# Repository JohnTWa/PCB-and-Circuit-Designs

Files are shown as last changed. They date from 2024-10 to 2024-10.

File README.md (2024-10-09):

All of these designs will work, however, the ones labelled "(OLD)" are projects which hit a dead end or were replaced with other designs.

Designs which were replaced by different designs as part of the same project will have "(Version #, OLD)" in the title. Only the version with the greatest number is currently up to date. 

ALl designs with "BEC" in the title are part of the Autonomous UAV project.

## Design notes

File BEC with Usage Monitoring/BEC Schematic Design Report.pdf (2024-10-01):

# Battery Eliminator Circuit (BEC) with Battery Monitoring

## John Walsh

October 1, 2024

As part of the autonomous UAV project, a Battery Eliminator Circuit (BEC) is required to provide 5 V and 3.3 V power to the servos, MCU and peripherals of the UAV, drawing power from a single LiPo battery while measuring the voltage and current for battery life calculation by the MCU. This is a basic document to cover just the circuit schematics. Bear in mind that the design may be changed substantially before the PCB layout is finalised.

## 1 5V and 3.3V Power

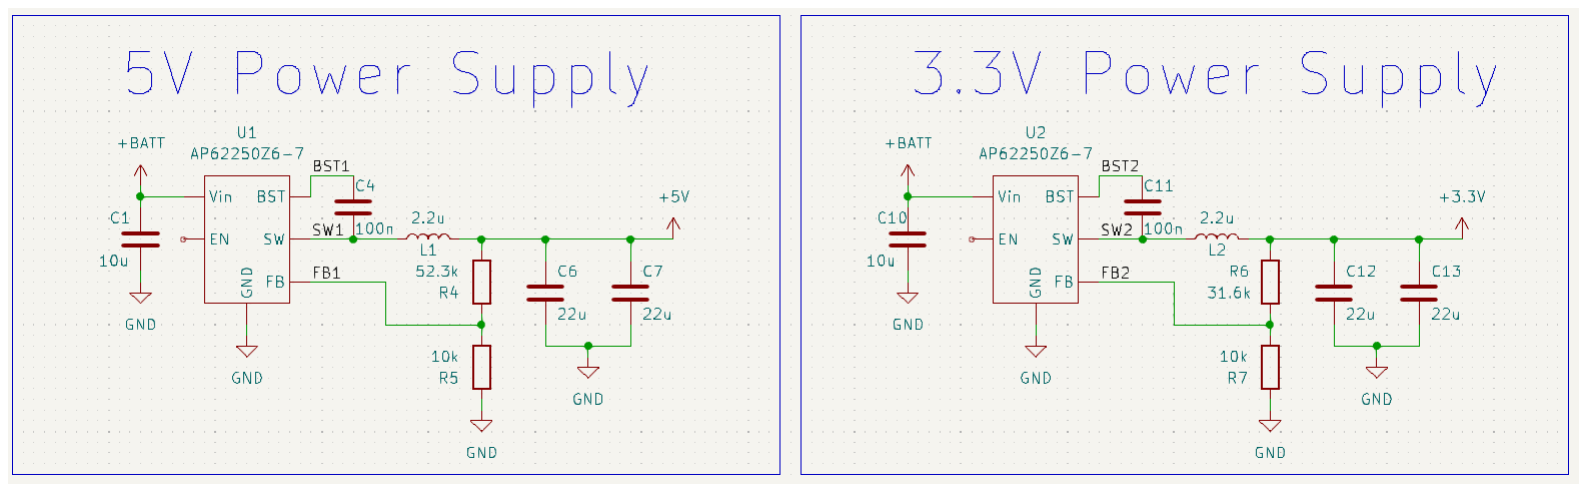
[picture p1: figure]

Figure 1: Power Supply Schematics

Two AP62250 power converters are used to provide both 5 V and 3.3 V power up to 2.5 A. Implementation is as directed in the datasheet [2], with potential dividers used to set output voltage. A 10 µF capacitor reduces both the surge current drawn from the input supply as well as the switching noise from the device and two 22 µF ceramic capacitors are used for output smoothing.

## 2 Voltage Measuring

At full charge, a LiPo battery has a potential VCELL = 4.2 V for each cell, or VBAT T = 12.6 V for a 3S battery. This value decreases non-linearly as the battery discharges. The battery may be damaged if it is discharged beyond the point at which VCELL = 3.0 V, so voltage is to be measured to ensure the UAV lands if VCELL < 3.3 V.

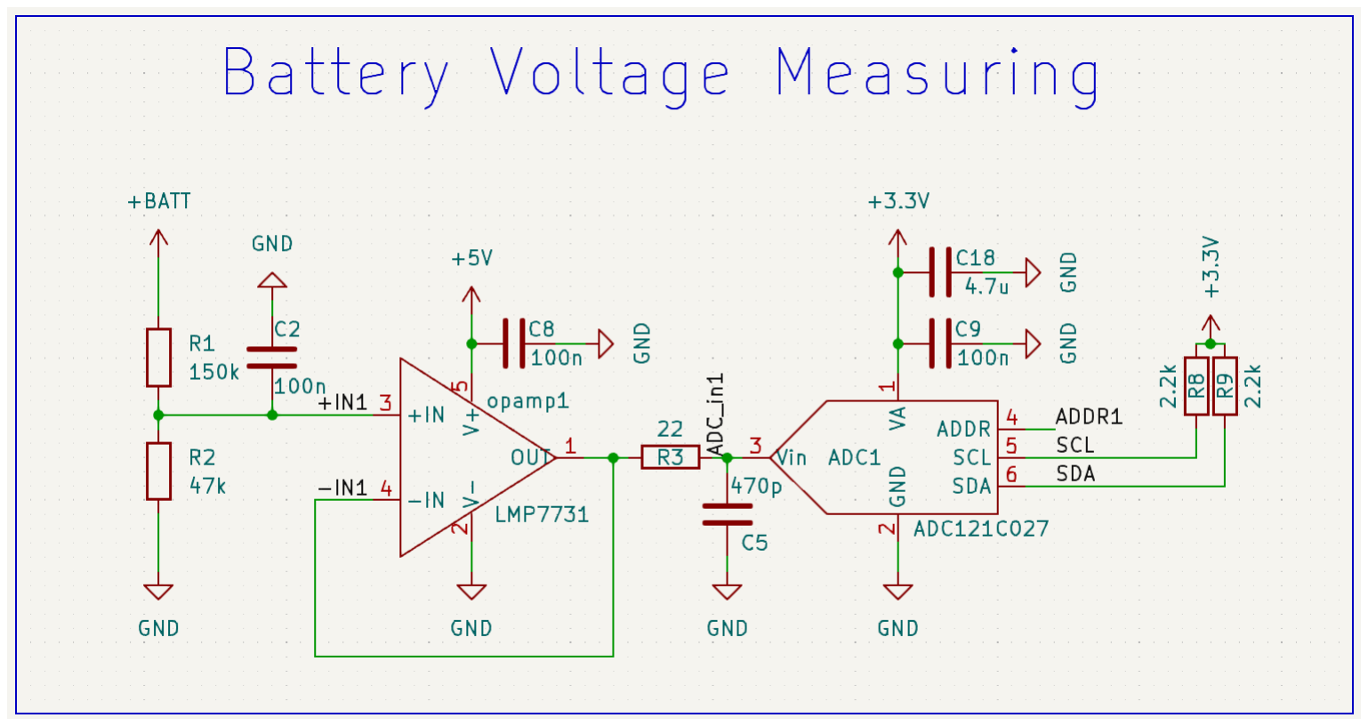
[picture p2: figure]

Figure 2: Voltage Measuring Circuit Schematic

This is implemented here using a potential divider, unity gain buffer and ADC. The unity buffer is required to provide a low-impedance signal to the ADC for measuring. It is implemented using the LMP7731 opamp, which takes power from the 5 V supply, giving a maximum input voltage of 3V without distortion [4]. From this the required resistances of the divider have been calculated, yielding 150 kΩ and 47 kΩ to give 3 V for a fully charged 3S battery. The potential divider can be expected to leak a maximum current of 64 mA, but this is acceptable given the expected maximum total current draw of 25 A for the UAV, and that the UAV is not intended to retain battery charge for long periods of time while idle. The 100 nF capacitor at the opamp +IN pin doubles as a ground bypass capacitor and a low pass filter in combination with the potential divider.
The 12-bit ADC121C021 draws power from the 3.3 V supply, which doubles as a reference. A 3 V reference was previously implemented but considered unnecessary given the limited requirement for accuracy and minimal improvement in resolution. Another low pass filter is implemented between the opamp and ADC, both to filter noise and to prevent voltage fluctuations with sampling, as per the ADC datasheet [3]. The I2C ADC output is pulled up to the 3.3 V supply.

## 3 Current Measuring

Each battery has a mAh rating given by the manufacturer, corresponding to the maximum current the battery can supply for a full hour. To track battery depletion, it is therefore possible to measure current supplied by the battery over time, and deduce from this how

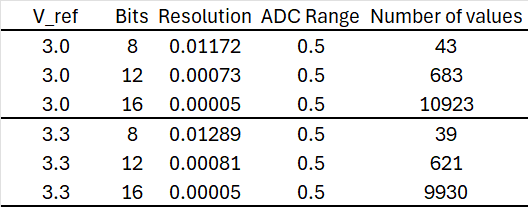
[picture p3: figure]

Table 1: Resolution and Number of Values for Voltage Measuring ADC

much charge is left. This method is significantly more reliable and less noisy than the voltage measuring method, but requires that motor power be routed directly through the board. This in turn causes problems with heat dissipation that must be considered when designing the PCB layout.

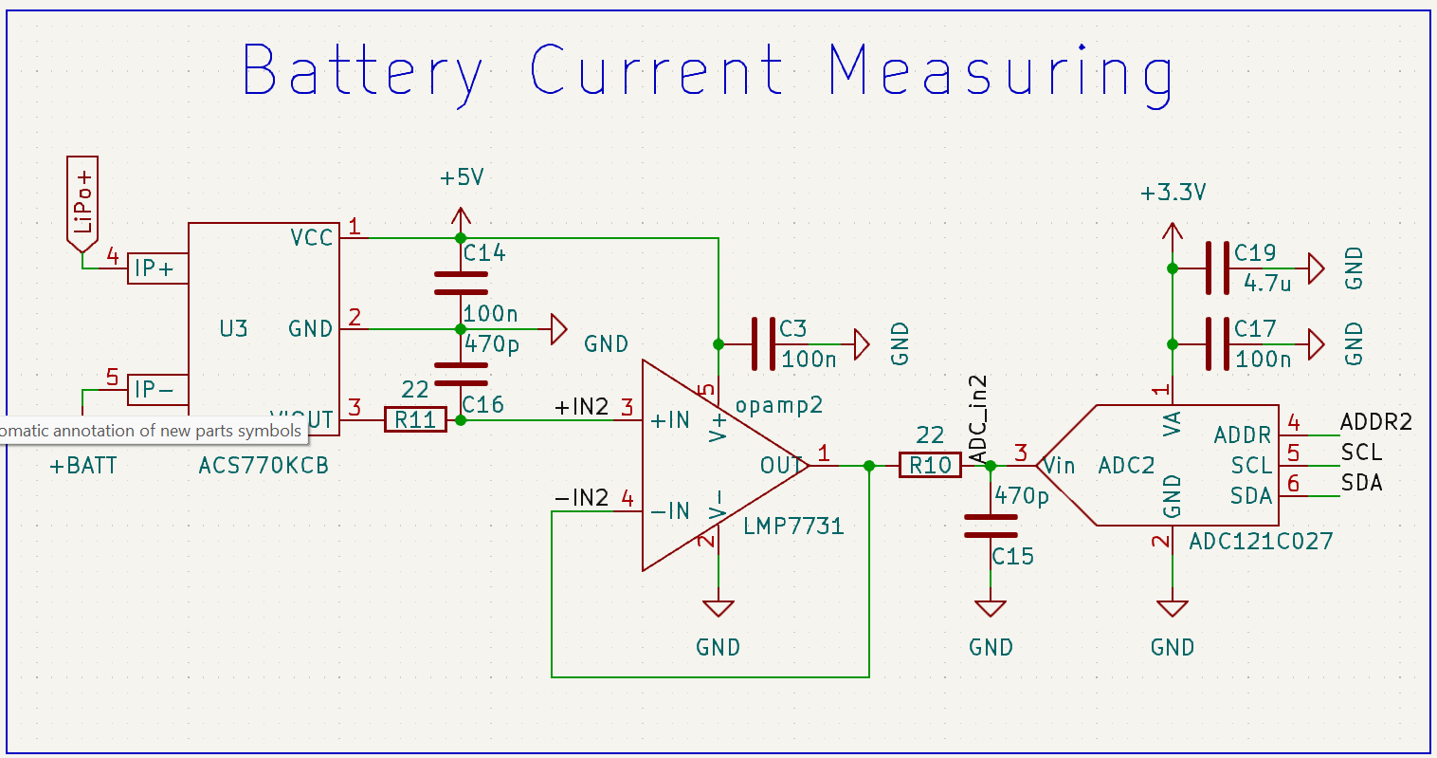
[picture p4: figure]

Figure 3: Current Measuring Schematic

In this design, the ACS770 hall-effect sensor is used to measure current from the battery. With a sensitivity of 80 mVA⁻¹
for the chosen variant (ACS770LCB-050U-PFF-T), output varies from 0 V to 2 V for the expected current draw of 0 A to 25 A [1]. This is then measured by the same measuring circuit as that described in Section 2. The ADDR pins of the ADCs allow each to be given different addresses, and therefore be used simultaneously.

## 4 Connectors

The BEC must be connected to the battery, ESCs and MCU board. There are therefore three connectors. The first connects to the LiPo battery, the second connects the LiPo battery to the ESCs (after the current measuring circuit) and the third, seven pin connector connects the power supplies and ADCs to the MCU. The battery and ESC connectors will be XT60

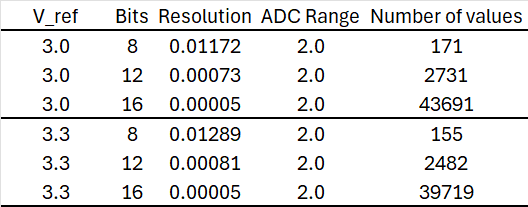
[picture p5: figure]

Table 2: Resolution and Number of Values for Current Measuring ADC

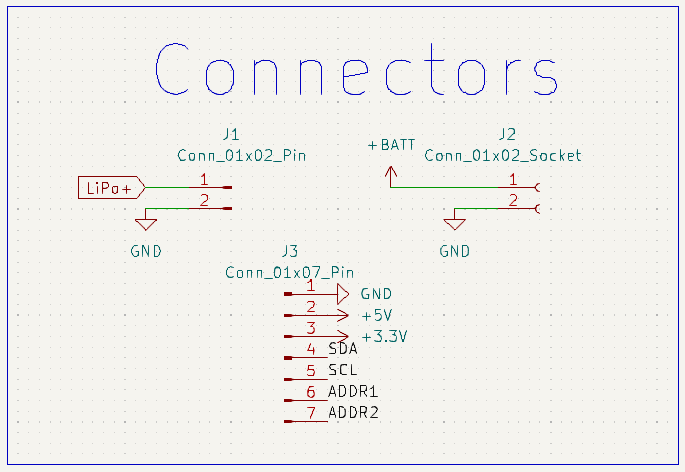
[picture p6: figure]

Figure 4: Board Connectors

connectors, as they are expected to carry up to 25A current. The MCU connector will be a JST-XH connector, as it is not required to carry more than 2.5A through any pin. JST-XH connectors have a pitch of 2.5mm, but are more vibration resistant than 2.54mm headers due to their casing and locking mechanism.

## References

[1] Allegro MicroSystems. ACS770 Thermally Enhanced, Fully Integrated, Hall-Effect-Based High-Precision Linear Current Sensor IC with 100 µOhm Current Conductor.

Rev. 13. July 2023. URL: https://www.allegromicro.com.

[2] Diodes Incorporated. AP62250 4.2V to 18V Input, 2.5A Low IQ Synchronous Buck Converter. Rev. 2. Jan. 2021. URL: https://www.diodes.com.
[3] Texas Instruments. ADC121C021/ADC121C021Q/ADC121C027 I2C-Compatible, 12-Bit ADC with Alert Function. Rev. F. Mar. 2013. URL: http : / / www . ti . com /

product/adc121c027. (http://www.ti.com/product/adc121c027)

[4] Texas Instruments. LMP7731 2.9 nV/Hz Low Noise, Precision, RRIO Amplifier. Rev. E.

Mar. 2013. URL: http://www.ti.com/product/lmp7731.

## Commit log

2024-08-31 Low Noise 5V Power Supply
    This simple circuit can deliver 5V low noise DC power at up to 1.2 Amps. Intended to power a precise measuring circuit from a 3S LiPo battery through a B8 connector wired to the screw terminals. Cannot be soldered by hand due to BGA power converter package.
2024-08-31 Low Noise 5V, 1.2A Power Supply Circuit Design
    This simple circuit design can deliver 5V low noise DC power at up to 1.2 Amps. Intended to power a precise measuring circuit from a 3S LiPo battery through a B8 connector wired to the screw terminals. Cannot be soldered by hand due to BGA power converter package.
    [Low Noise Supply.kicad_sch]
2024-10-01 Rename Low Noise 5V Power Supply.asc to Low Noise 5V Power Supply/LTSpice Schematic
2024-10-01 Rename Low Noise Power.asc to Low Noise 5V Power Supply/Low Noise Power.asc
2024-10-01 Update and rename Low Noise Supply.kicad_sch to Low Noise 5V Power Supply/KiCad_Schematic.kicad_sch
    [KiCad_Schematic.kicad_sch]
2024-10-01 Battery Eliminator Circuit with Usage Monitoring
    [Through Power Experiment.kicad_sch]
2024-10-01 Update and rename Through Power Experiment.kicad_sch to Battery Eliminator with Usage Monitoring/BEC.kicad_sch
    [BEC.kicad_sch]
2024-10-01 Added BEC schematic design report
2024-10-09 Update and rename Low Noise 5V Power Supply/KiCad_Schematic.kicad_sch to Low Noise 5V Power Supply (OLD)KiCad_Schematic.kicad_sch
    [Low Noise 5V Power Supply (OLD)KiCad_Schematic.kicad_sch]
2024-10-09 Update and rename Low Noise 5V Power Supply (OLD)KiCad_Schematic.kicad_sch to Low Noise 5V Power Supply (OLD)/KiCad_Schematic.kicad_sch
    [KiCad_Schematic.kicad_sch]
2024-10-09 Rename LTSpice Schematic to LTSpice Schematic
2024-10-09 Rename Low Noise Power.asc to Low Noise Power.asc
2024-10-09 Rename BEC Schematic Design Report.pdf to BEC Schematic Design Report.pdf
2024-10-09 Update and rename BEC.kicad_sch
    [BEC.kicad_sch]
